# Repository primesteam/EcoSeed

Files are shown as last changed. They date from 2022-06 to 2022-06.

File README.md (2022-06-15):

# EcoSeed
Every plant needs a someone to keep an eye on it. Or maybe something? 

logo-new
# Abstract
**EcoSeed** is an eco friendly system that takes good care of your plant. The system consists of several sensors 
used to monitor specific factors of the growth rate of a plant, such as its weight and height. Moreover, EcoSeed is
able to take care of the plant, providing water whenever needed and turning the pot to the point where the amount
of sunlight is highest. Last but not least, our system collects all the measured values to a database, providing the
users with information for study and data mining. 

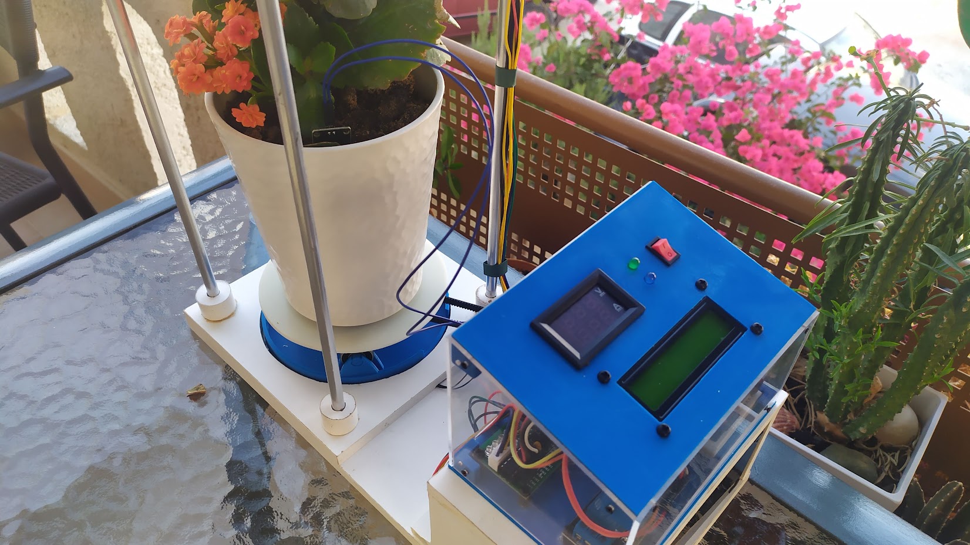
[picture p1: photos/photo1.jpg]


# Components
**Ecoseed** is a wooden-plastic making, mainly consisting of two parts:
#### The base
On one side, there is the base on which the flowerpot is placed. At the top of the base, you can find a stepper with an 
LDR sensor on it. This part continuously rotates to detect the best direction based of the maximum amount of sunlight. 
The base sits on three bearings which help it to rotatethe flowerpot easily. Next to the base there is another stepper 
motor, which rotates the flowerpot towards the direction detected.

Bottom part of the base             |  Top part of the base
:-------------------------:|:-------------------------:
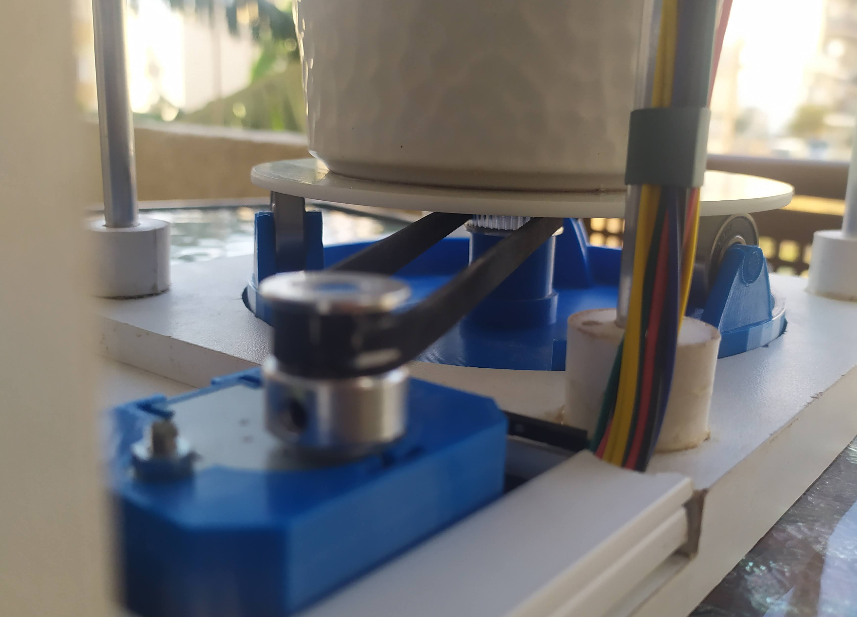
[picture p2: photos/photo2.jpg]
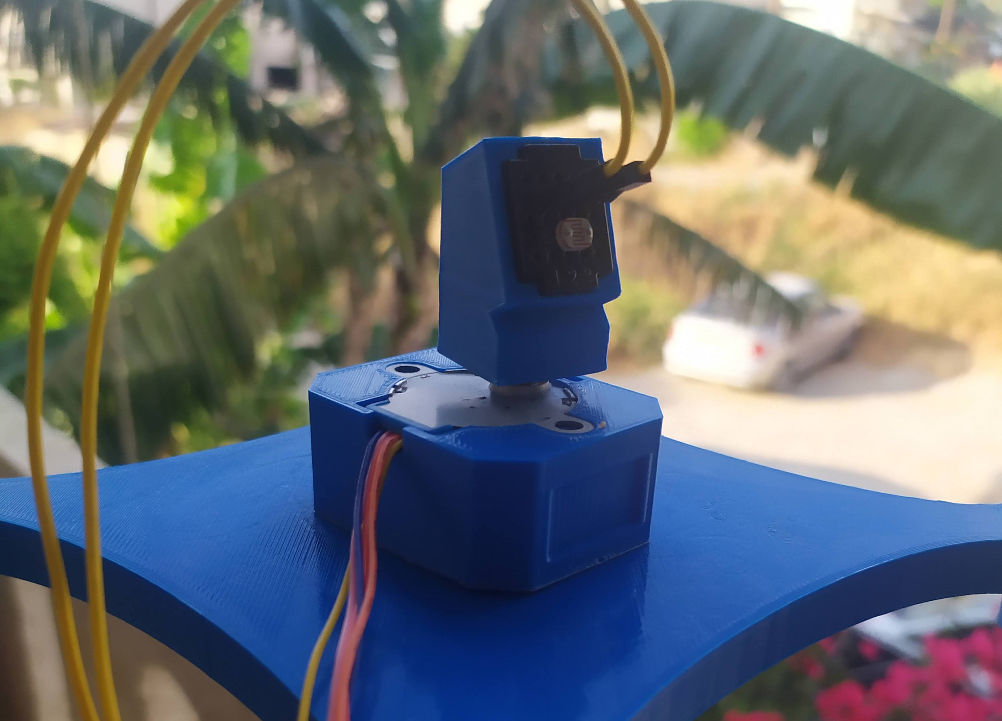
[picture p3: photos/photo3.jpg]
  |  

Bellow the base, you will find a force sensor which is used to calculate the weight of the plant. Last, under the top
part of the base, there is an ultrasonic sensor which helps to calculate the height of the plant.

Force sensor             |  Ultrasonic sensor
:-------------------------:|:-------------------------:
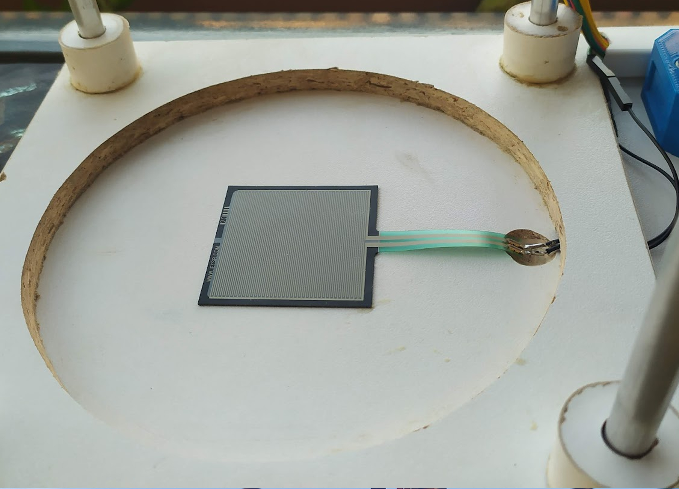
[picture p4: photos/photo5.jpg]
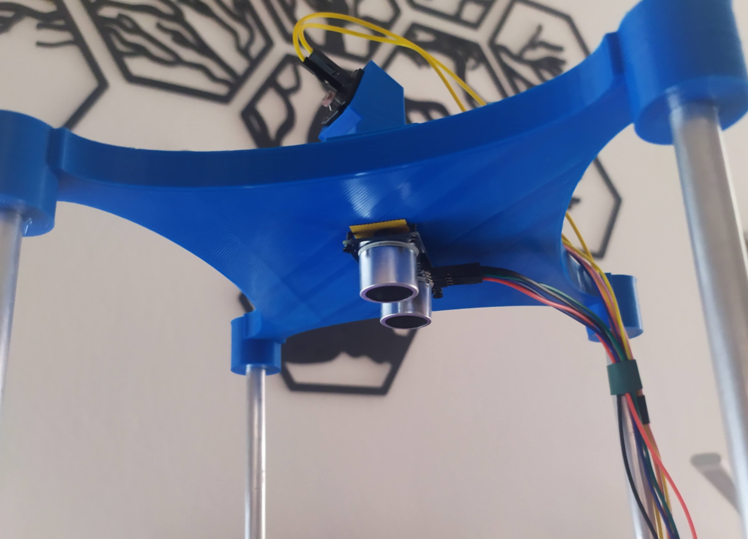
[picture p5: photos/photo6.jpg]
  |  

#### The control panel
On the other side, there is the control panel, an enclosure made of plastic and plexiglas on top of a 12V battery. The 
control panel contains the rest of the electronic components of the system:
- <b>ESP32</b> (the micro-controller responsible for the functionality of the system)
- <b>Controllers</b> for the two steppers
- <b>Relay module</b> (used to control the water pump)
- <b>RTC module</b> (used to record the measured values every two hours)
- <b>Soil moisture</b> sensor controller
- <b>Step-down</b> module (to convert battery's 12V to 5V needed)
- <b>Voltmeter</b> (to check the circuit's voltage)
- <b>LCD display</b> (to monitor measured values in real time) 

Top view             |  Side view
:-------------------------:|:-------------------------:
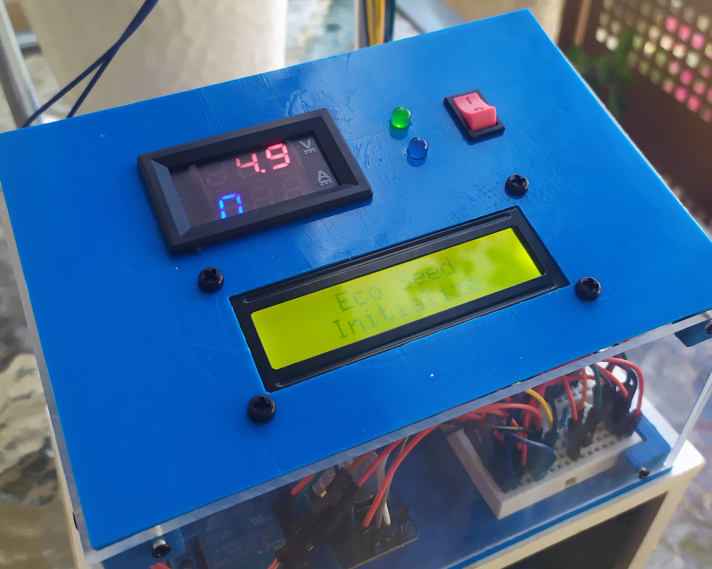
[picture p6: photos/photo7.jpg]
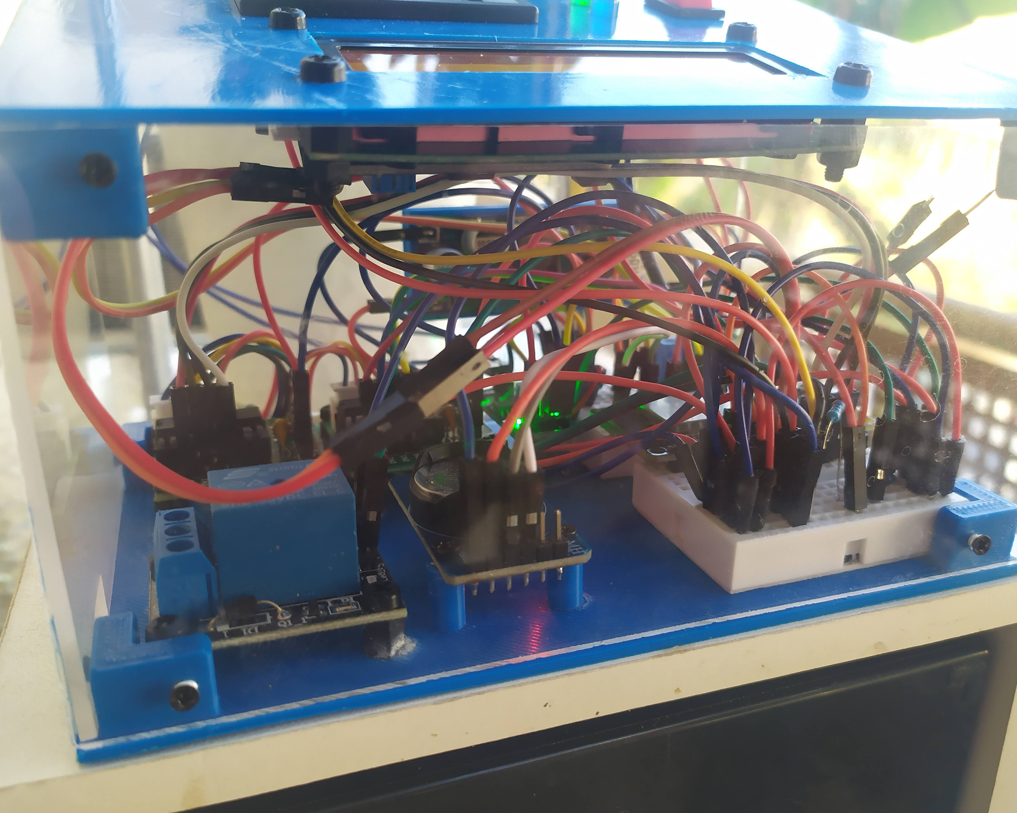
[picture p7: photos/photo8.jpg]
  |  

All the plastic parts were printed with PLA on an Ender 3 pro 3D printer. All the models were custom made by our team.
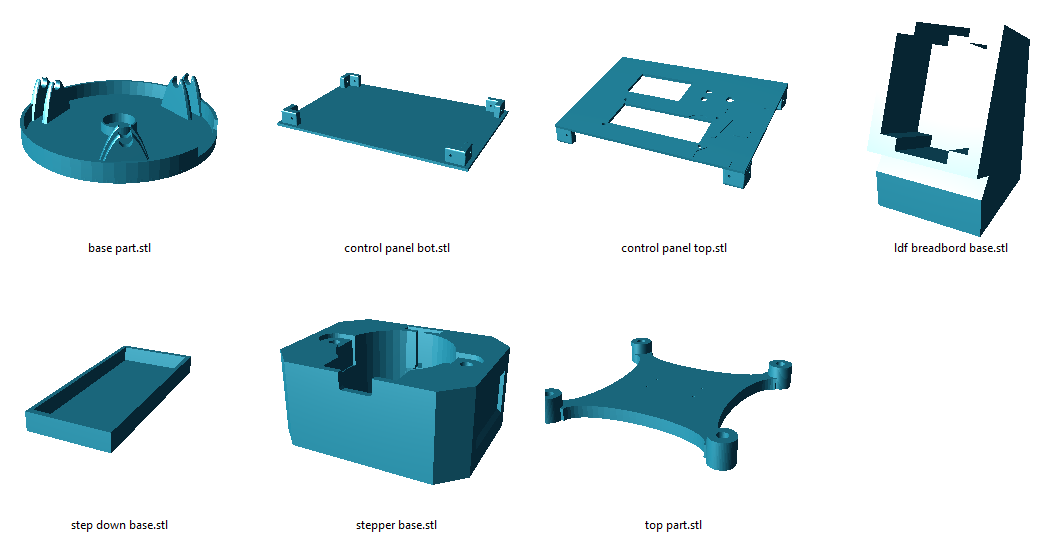
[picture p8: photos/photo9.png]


# Functionality
Like every micro-controller, **EcoSeed** performs in a loop. Thus, it first initializes the necessary modules
and then repeatedly does the following actions:
- rotates the stepper motor with the LDR sensor to detect the best direction according to the sunlight
- rotates the flowerpot stepper motor if necessary
- measures the height, weight and moisture
- if the time is right, sends the measured data to the server database
- updates the LCD display with the measured data

At any time, the user can check the collected data in a page of our server.
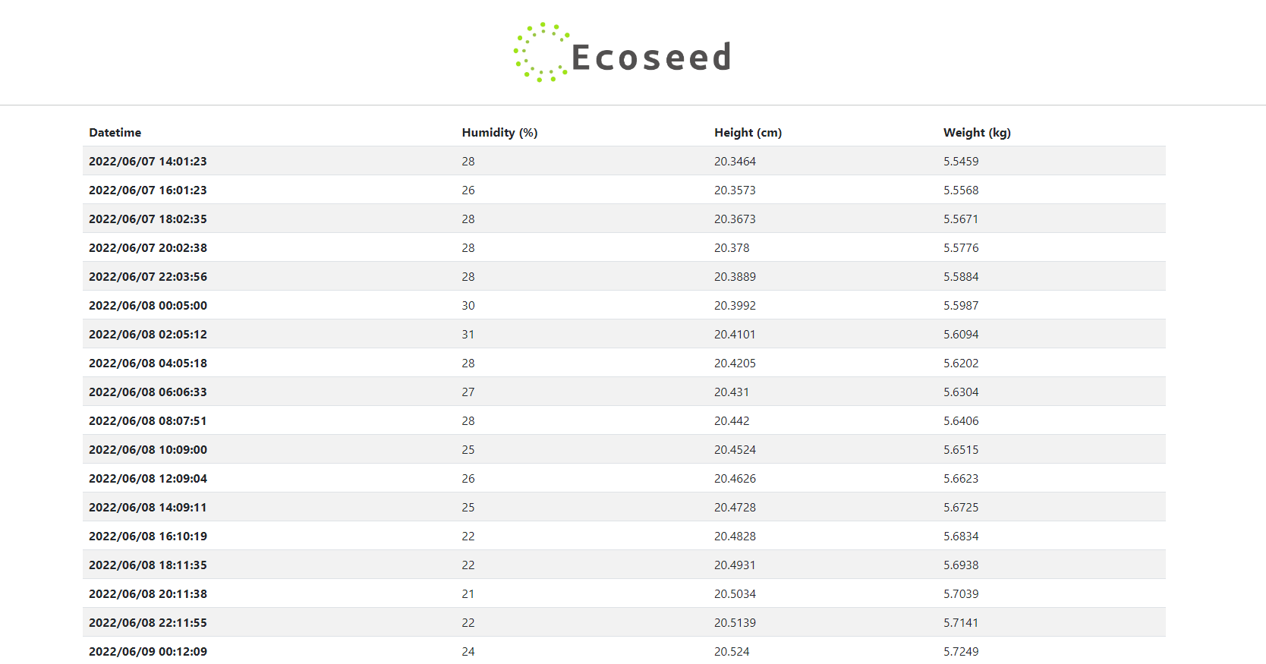
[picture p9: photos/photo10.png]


# Future Work
During the development of **EcoSeed** various ideas came to our minds as improvements to our system. Since we
established a connection with a server, we could make our system a bit more clever. We could store more data in
our database and, according to the plant species in the pot, the system would provide the amount of water or any
other required ingredients, based on data stored in our database. Moreover, a camera could be attached to take
pictures of the plant several times during a day. We would be more than happy to hear your input on our system.

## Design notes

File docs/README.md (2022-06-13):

# Code Explanation

## Files

* <a href="#main-file">Main File</a>
* <a href="#declare_location-function">declare_location()</a>
* <a href="#data_post-function">data_post()</a>
* <a href="#wifi_led-function">wifi_led()</a>
* <a href="#lcd_stats-function">lcd_stats()</a>
* <a href="#lcd_welcome-function">lcd_welcome()</a>
* <a href="#moisture-function">moisture()</a>
* <a href="#get_distance-function">get_distance()</a>

## Main File

### _Include Project Libraries_

```cpp
#include <Stepper.h> // Stepper Library
#include <LiquidCrystal_I2C.h> // LiquidCrystal for I2C Library
#include <WiFi.h> // WiFi Library
#include <HTTPClient.h> // HTTPClient Library
#include <Wire.h> // Wire Library
#include "RTClib.h" // RTClib Library
```

### _Define RTC_

```cpp
RTC_DS3231 rtc; // Define RTC
DateTime now; // ESP32 Time
```

### _Define WiFi Settings_

```cpp
// WiFi
const char* ssid = ""; // SSID for the WiFi
const char* password = ""; // Password for the WiFi
const char* serverName = "ecoseed**.com"; // Define the Server for the data
```

### _Define Component Pins_

```cpp
// Ldr Sensor
const int ldrPin = 4; // LDR Sensor Pin

// Moisture Sensor
int sensor_pin = 34; // Moisture Sensor Pin

// Force Sensor
const int forcePin = 32; // Force Sensor Pin

// Ultrasonic Sensor
const int trigPin = 33; // Trigger Pin
const int echoPin = 25; // Echo Pin
#define SOUND_SPEED 0.034 // Sound Speed

// Leds
const int led = 26; // LED Pin

// Relay
const int relayPin = 2; // Relay Pin
```

### _Create LCD_

```cpp
// Lcd I2c
const int lcdColumns = 16; // Define the Number of Columns for the LCD
const int lcdRows = 2; // Define the Number of Rows for the LCD
LiquidCrystal_I2C lcd(0x27, lcdColumns, lcdRows); // Create the LCD
```

### _Create Stepper_

```cpp
// Steppers
#define S1IN1 13 // IN1 for the 1st Stepper
#define S1IN2 12 // IN2 for the 1st Stepper
#define S1IN3 14 // IN3 for the 1st Stepper
#define S1IN4 27 // IN4 for the 1st Stepper

#define S2IN1 18 // IN1 for the 2st Stepper
#define S2IN2 5 // IN2 for the 2st Stepper
#define S2IN3 17 // IN3 for the 2st Stepper
#define S2IN4 16 // IN4 for the 2st Stepper
const int stepsPerRevolution = 2048; // Steps per Revolution
Stepper ldrStepper(stepsPerRevolution, S1IN1, S1IN3, S1IN2, S1IN4); // Create 1st Stepper
Stepper plantStepper(stepsPerRevolution, S2IN1, S2IN3, S2IN2, S2IN4); // Create 2st Stepper
```

### _Open Setup Function_

```cpp
void setup() {
```

#### Begin Serial

```cpp
  Serial.begin(115200);
```

#### Start LCD

```cpp
  lcd.init();
```

#### Enable Backlight of LCD

```cpp
  lcd.backlight();
```

#### Show Welcome Text on LCD

```cpp
  lcd_welcome();
```

#### Check RTC Module

```cpp
  if (! rtc.begin()) {
    Serial.println("Couldn't find RTC");
  }
```

#### Set Pin Modes

```cpp
  // LED Mode
  pinMode(led, OUTPUT);
  // Trigger Mode
  pinMode(trigPin, OUTPUT);
  // Echo Mode
  pinMode(echoPin, INPUT);
```

#### Set Steppers' Speeds

```cpp
  // 1st Stepper Speed
  ldrStepper.setSpeed(10);
  // 2st Stepper Speed
  plantStepper.setSpeed(10);
```

#### Begin Wi-Fi and Check for its Status

```cpp
  WiFi.begin(ssid, password);
  Serial.println("Connecting");
  while (WiFi.status() != WL_CONNECTED) {
    delay(500);
    Serial.print(".");
  }
```

#### Print the IP of the ESP32 to the Console

```cpp
  Serial.println("");
  Serial.print("Connected to WiFi network with IP Address: ");
  Serial.println(WiFi.localIP());
```

#### Adjust System Time and Close Setup Function

```cpp
  rtc.adjust(DateTime(F(__DATE__), F(__TIME__)));
}
```

### _Open Loop Function_

```cpp
void loop() {
```

#### Define ESP32 time through RTC

```cpp
  now = rtc.now();
```

#### Call Functions

```cpp
  declare_location();
  data_post();
  wifi_led();
  lcd_stats();
```

#### Wait 1 Second and Close Loop Function

```cpp
  delay(1000);
}
```

## declare_location Function

### _Define Variables_

```cpp
int stops = 10;
int ldrmax = 0;
int steppos = 0;
int current = 0;
```

### _Create Function_

```cpp
void declare_location() {
```

### _Rotate 1st Stepper Clockwise_

```cpp
  for (int i = 0; i < (stops / 2 + 1); i++) {
    int l = analogRead(ldrPin); // Get LDR Value
    if (l > ldrmax) { // Check if the value is greater that the variable
      ldrmax = l; // Save value
      steppos = (stepsPerRevolution / stops) * i; // Save position
    }
    ldrStepper.step(stepsPerRevolution / stops); // Turn Stepper One Step
    delay(500);
  }
  ldrStepper.step(-(stepsPerRevolution / stops) * 5); // Return Stepper to its original position
```

### _Rotate 1st Stepper Counterclockwise_

```cpp
  for (int i = 0; i < (stops / 2 + 1); i++) {
    int l = analogRead(ldrPin); // Get LDR Value
    if (l > ldrmax) { // Check if the value is greater that the variable
      ldrmax = l; // Save value
      steppos = (-stepsPerRevolution / stops) * i; // Save position
    }
    ldrStepper.step(-stepsPerRevolution / stops); // Turn Stepper One Step
    delay(500);
  }
  ldrStepper.step((stepsPerRevolution / stops) * 5); // Return Stepper to its original position
```

### _Turn 2nd Stepper For the First Time_

```cpp
  if (current == 0) {
    plantStepper.step(steppos * 1.8);
    current = steppos * 1.8;
  } 
```

### _Turn 2nd Stepper_

```cpp
  else {
    plantStepper.step(-current);
    current = steppos * 1.8;
    plantStepper.step(steppos * 1.8);
  }
```

### _Close Function_

```cpp
}
```

## data_post Function

### _Define Variables_

```cpp
int logged = 0;
```

### _Create Function_

```cpp
void data_post() {
```

### _Check if it's the time to post data_

```cpp
  if (now.hour() % 2 == 0 and logged == 0) {
```

### _Check for Wi-Fi_

```cpp
    if (WiFi.status() == WL_CONNECTED) {
```

### _Define Clients_

```cpp
      WiFiClient client;
      HTTPClient http;
```

### _Begin HTTP Server_

```cpp
      http.begin(client, serverName);
```

### _Define Strings_

```cpp
      String weight = "weight=" + String(analogRead(forcePin));
      String humidity = "humidity=" + moisture();
      String height = "height=" + get_distance();
```

### _Define Request Data_

```cpp
      http.addHeader("Content-Type", "application/x-www-form-urlencoded");
      String httpRequestData = humidity + "&" + height + "&" + weight;
      int httpResponseCode = http.POST(httpRequestData);
```

### _Print Responce Code to Console_

```cpp
      Serial.print("HTTP Response code: ");
      Serial.println(httpResponseCode);
      logged = 1;
      http.end();
    }
```

### _Wi-Fi Disconnected_

```cpp
    else {
      Serial.println("WiFi Disconnected");
    }
```

### _Check for Odd Hour_

```cpp
  } else if (now.hour() % 2 == 1) {
    logged = 0;
  }
```

### _Close Function_

```cpp
}
```

## wifi_led Function

### _Create Function and blink the led_

```cpp
void wifi_led() {
  digitalWrite(led, HIGH);
  delay(500);
  digitalWrite(led, LOW);
  delay(500);
}
```

## lcd_stats Function

### _Create Function and Clear LCD Screen_

```cpp
void lcd_stats(){
  lcd.clear();
```

### _Set Cursor and write the Weight_

```cpp
  lcd.setCursor(0, 0);
  lcd.print("W: " + String(analogRead(forcePin)));
```

### _Set Cursor and Write the Humidity_

```cpp
  lcd.setCursor(8,0);
  lcd.print("H: " + moisture() + "%");
```

### _Set Cursor and Write the Height_

```cpp
  lcd.setCursor(0,1);
  lcd.print("H: " + get_distance() + "cm");
```

### _Close Function_

```cpp
}
```

## lcd_welcome Function

### _Create Function and Clear LCD Screen_

```cpp
void lcd_welcome() {
  lcd.clear();
```

### _Set Cursor and Write Text_

```cpp
  lcd.setCursor(4, 0);
  lcd.print("Eco Seed");
  lcd.setCursor(3, 1);
  lcd.print("Initialize");
  delay(1000);
```

### _Close Function_

```cpp
}
```

## moisture Function

### _Create Function_

```cpp
String moisture() {
```

### _Get sensor value and Convert it to percentage_

```cpp
  int value = analogRead(sensor_pin);
  value = map(value, 4095, 1500, 0, 100);
  return String(value);
```

### _Close Function_

```cpp
}
```

## get_distance Function

### _Create Function_

```cpp
String get_distance() {
```

### _Write Ultrasonic Sensor Pins_

```cpp
  digitalWrite(trigPin, LOW);
  delayMicroseconds(2);
  digitalWrite(trigPin, HIGH);
  delayMicroseconds(10);
  digitalWrite(trigPin, LOW);

```

### _Measure Sensor Values_

```cpp
  long duration = pulseIn(echoPin, HIGH);
  float distanceCm = duration * SOUND_SPEED / 2;
  return String(distanceCm);
}
```

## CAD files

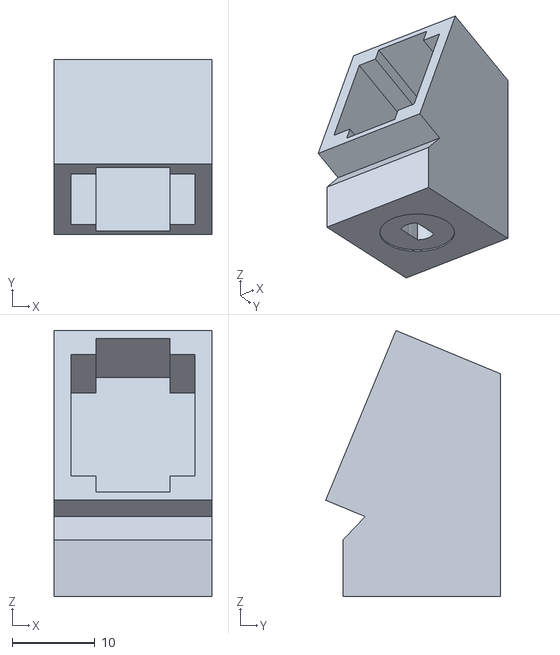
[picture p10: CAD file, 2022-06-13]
stl/ldr breadboard base.stl
19.0 x 21.1 x 32.1

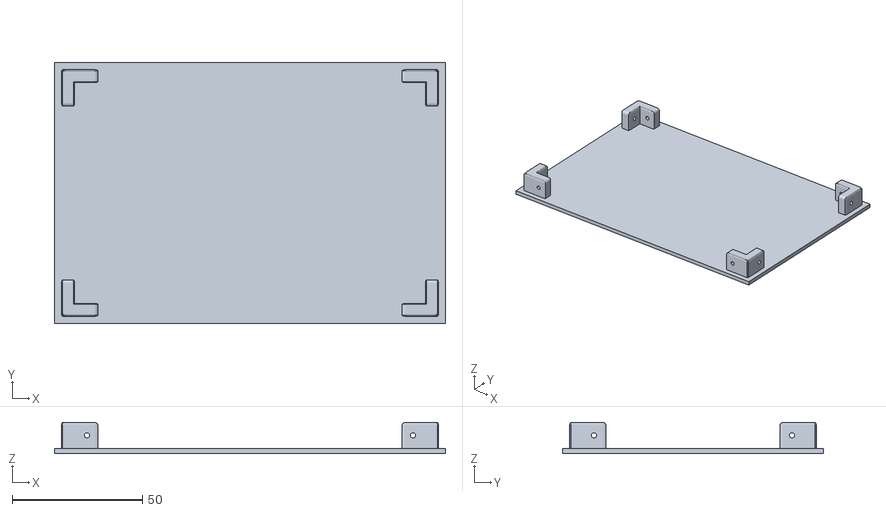
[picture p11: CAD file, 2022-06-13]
stl/control panel base.stl
150.0 x 100.0 x 12.0

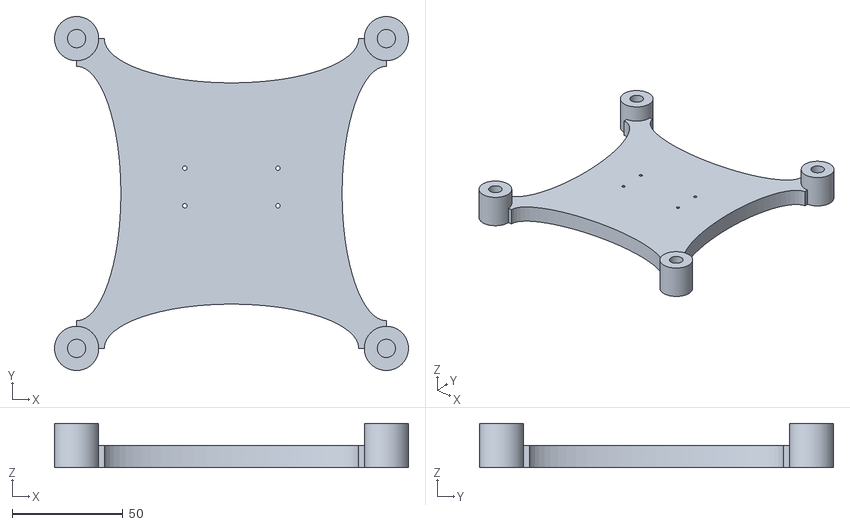
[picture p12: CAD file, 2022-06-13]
stl/top part.stl
160.0 x 160.0 x 20.0

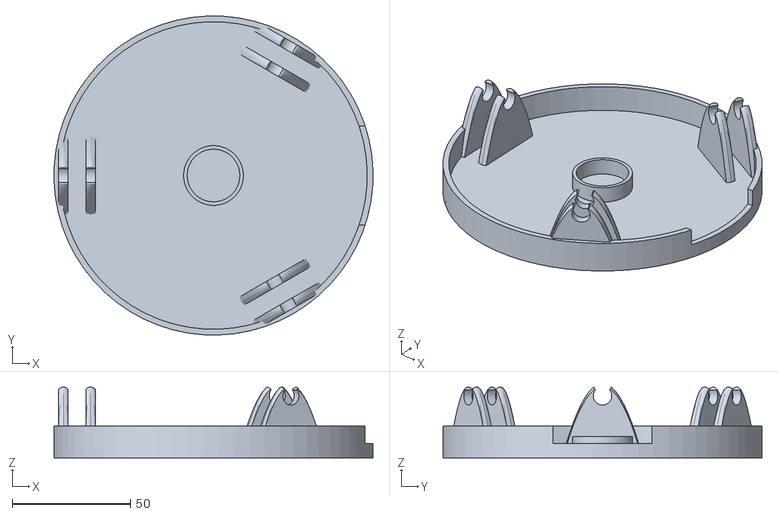
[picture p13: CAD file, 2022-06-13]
stl/plant base.stl
135.0 x 135.0 x 30.0

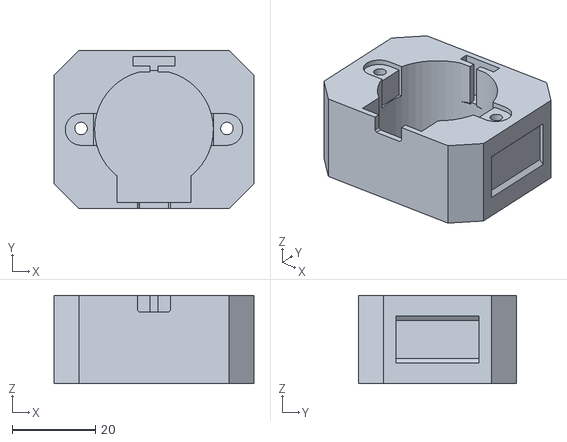
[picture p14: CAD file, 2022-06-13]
stl/stepper base.stl
48.0 x 38.0 x 21.2

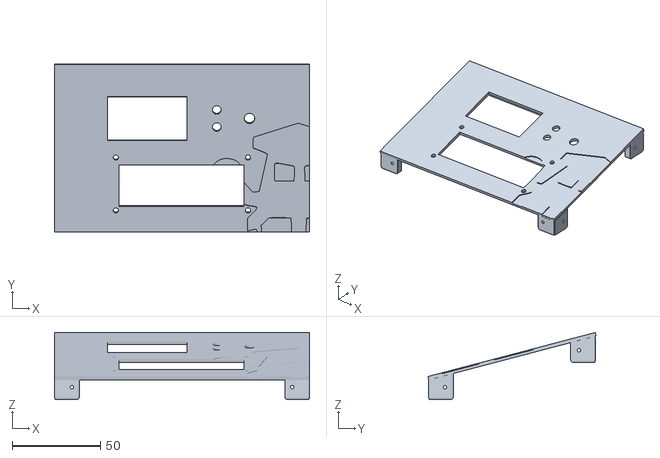
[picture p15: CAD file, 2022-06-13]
stl/control panel top.stl
144.7 x 95.5 x 38.0

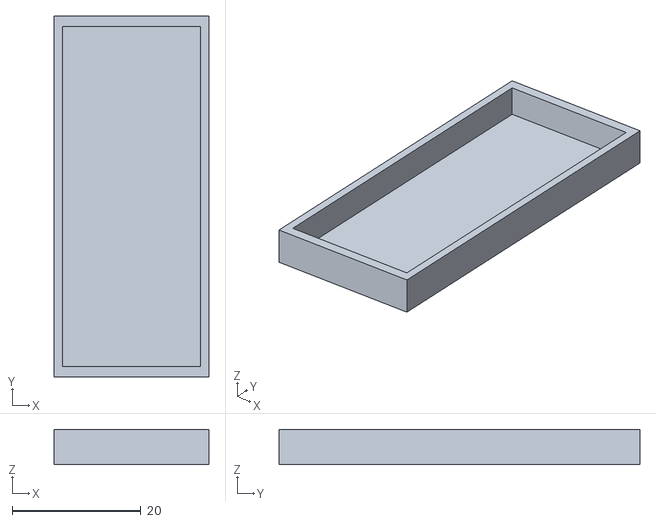
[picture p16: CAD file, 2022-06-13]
stl/step down base.stl
24.0 x 56.0 x 5.50

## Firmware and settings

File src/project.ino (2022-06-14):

#include <Stepper.h> // Stepper Library
#include <LiquidCrystal_I2C.h> // LiquidCrystal for I2C Library
#include <WiFi.h> // WiFi Library
#include <HTTPClient.h> // HTTPClient Library
#include <Wire.h> // Wire Library
#include "RTClib.h" // RTClib Library

RTC_DS3231 rtc; // Define RTC
DateTime now; // ESP32 Time

// WiFi
const char* ssid = ""; // SSID for the WiFi
const char* password = ""; // Define the Password for the WiFi
const char* serverName = "ecoseed**.com"; // Define the Server for the data

// Ldr Sensor
const int ldrPin = 4;

// Moisture Sensor
int sensor_pin = 34;

// Force Sensor
const int forcePin = 32;

// Ultrasonic Sensor
const int trigPin = 33;
const int echoPin = 25;
#define SOUND_SPEED 0.034 // Sound Speed

// Leds
const int led = 26;

// Relay
const int relayPin = 2;

// Lcd I2c
const int lcdColumns = 16;
const int lcdRows = 2;
LiquidCrystal_I2C lcd(0x27, lcdColumns, lcdRows);

// Steppers
#define S1IN1 13 // IN1 for the 1st Stepper
#define S1IN2 12 // IN2 for the 1st Stepper
#define S1IN3 14 // IN3 for the 1st Stepper
#define S1IN4 27 // IN4 for the 1st Stepper

#define S2IN1 18 // IN1 for the 2st Stepper
#define S2IN2 5 // IN2 for the 2st Stepper
#define S2IN3 17 // IN3 for the 2st Stepper
#define S2IN4 16 // IN4 for the 2st Stepper
const int stepsPerRevolution = 2048;
// Create Steppers
Stepper ldrStepper(stepsPerRevolution, S1IN1, S1IN3, S1IN2, S1IN4);
Stepper plantStepper(stepsPerRevolution, S2IN1, S2IN3, S2IN2, S2IN4);

void setup() {
  // Begin Serial
  Serial.begin(115200);

  lcd.init(); // Start LCD
  lcd.backlight(); // Enable Backlight of LCD
  // Show Welcome Text on LCD
  lcd_welcome();

  if (! rtc.begin()) { // Check RTC Module
    Serial.println("Couldn't find RTC");
  }

  // LED Mode
  pinMode(led, OUTPUT);
  // Trigger Mode
  pinMode(trigPin, OUTPUT);
  // Echo Mode
  pinMode(echoPin, INPUT);

  // Set Speeds
  ldrStepper.setSpeed(10);
  plantStepper.setSpeed(10); // 2st Stepper Speed

  // Begin Wi-Fi
  WiFi.begin(ssid, password);
  Serial.println("Connecting");
  while (WiFi.status() != WL_CONNECTED) { // Check for WiFi status
    delay(500);
    Serial.print(".");
  }

  // Print the IP of the ESP32 to the Console
  Serial.println("");
  Serial.print("Connected to WiFi network with IP Address: ");
  Serial.println(WiFi.localIP());

  rtc.adjust(DateTime(F(__DATE__), F(__TIME__))); // Adjust System Time

}

void loop() {
  now = rtc.now(); // Define ESP32 time through RTC

  // Call Functions
  declare_location();
  data_post();
  wifi_led();
  lcd_stats();

  delay(1000); // Wait 1 Second
}

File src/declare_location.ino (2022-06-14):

// Define Variables
int stops = 10;
int ldrmax = 0;
int steppos = 0;
int current = 0;

void declare_location() {
  // Rotate 1st Stepper Clockwise
  for (int i = 0; i < (stops / 2 + 1); i++) {
    int l = analogRead(ldrPin);
    if (l > ldrmax) {
      ldrmax = l;
      steppos = (stepsPerRevolution / stops) * i;
    }
    ldrStepper.step(stepsPerRevolution / stops);
    delay(500);
  }
  ldrStepper.step(-(stepsPerRevolution / stops) * 5);

  // Rotate 1st Stepper Counterclockwise
  for (int i = 0; i < (stops / 2 + 1); i++) {
    int l = analogRead(ldrPin);
    if (l > ldrmax) {
      ldrmax = l;
      steppos = (-stepsPerRevolution / stops) * i;
    }
    ldrStepper.step(-stepsPerRevolution / stops);
    delay(500);
  }
  ldrStepper.step((stepsPerRevolution / stops) * 5);

  // Turn 2nd Stepper For the First Time
  if (current == 0) {
    plantStepper.step(steppos * 1.8);
    current = steppos * 1.8;
  }
  else { // Turn 2nd Stepper
    plantStepper.step(-current);
    current = steppos * 1.8;
    plantStepper.step(steppos * 1.8);
  }
}
